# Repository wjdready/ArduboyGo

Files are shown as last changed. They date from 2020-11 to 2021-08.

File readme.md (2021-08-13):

### ArduboyGo

这是一个基于开源游戏机Arduboy制作的Arduboy Go, 这个项目由个人兴趣所产生, 目前已经完全开源包括硬件设计，外壳和代码。
目前该项目有3个版本:
  * V2 最早的一代, 不支持外置 FLASH
  
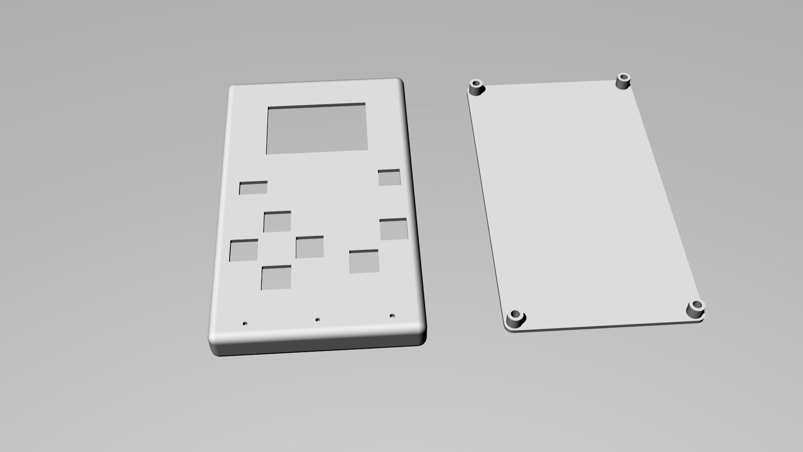
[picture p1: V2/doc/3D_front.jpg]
  

  * V3 支持外置 FLASH 加载游戏, 自定义外壳
  
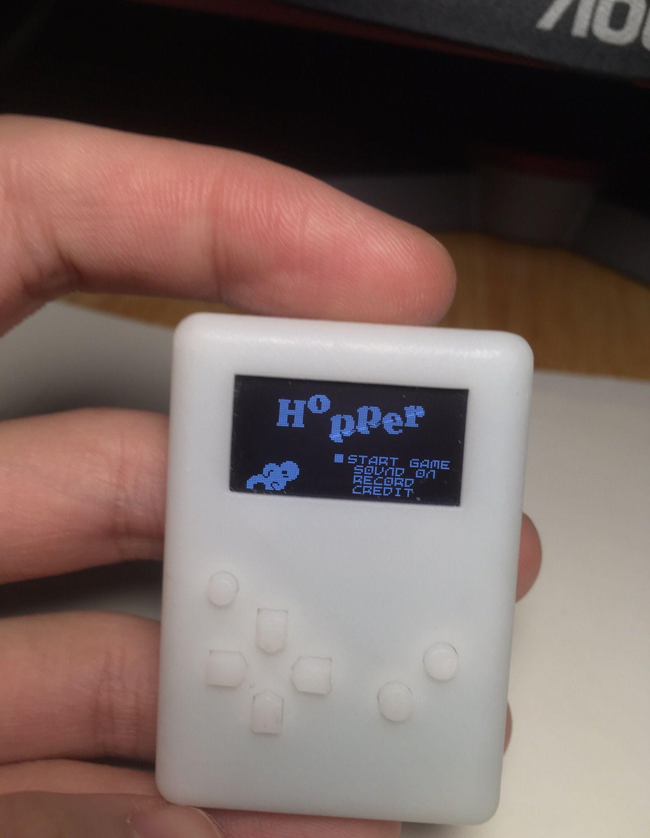
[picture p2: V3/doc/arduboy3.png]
  

  * V4 采用现成外壳, 类似于GBA
  
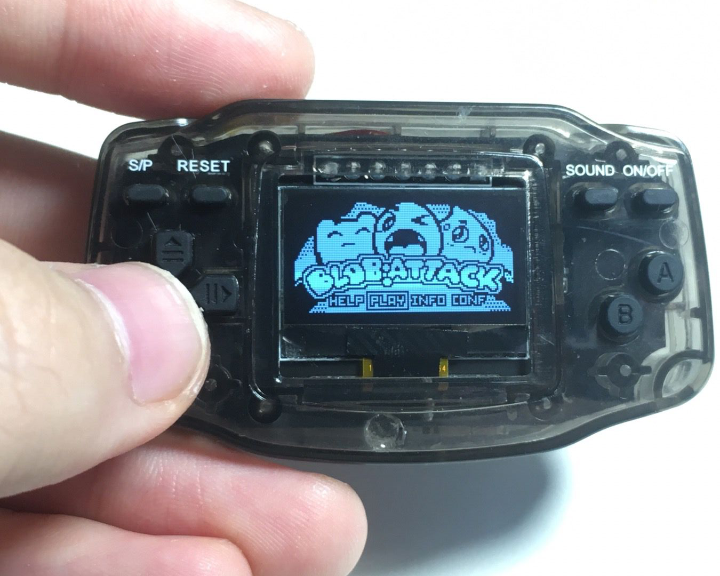
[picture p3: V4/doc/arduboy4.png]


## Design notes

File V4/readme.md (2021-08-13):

### Arduboy V4 版本
V4 版本分成两块板子, 一个是底板, 一个是 OLED, 外壳使用[现成的](https://s.taobao.com/search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)模型改造而来

  
  
* Bootloader 下载和配料清单参考 V3 版本. 因为只是外形改变, 功能和电路几乎一致. 
* 制作过程见[Bilibili](https://www.bilibili.com/video/BV1QK4y1H7EQ)

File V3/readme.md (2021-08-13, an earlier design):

### Arduboy V3 版本

该版本加入了 SPI FLASH, 可存储几百个游戏。



* 文件说明
  * Gerber 用于PCB打样
  * 3D 文件用于打印外壳
  * 可按照BOM 表提供的链接购买元件

* 制造 (非广告)
  * 可选3D 打印厂家, [未来工厂](www.wenext.cn)
  * 可选PCB加工厂, [嘉立创](www.jlc.com)
  * [bootloader 烧录器](https://item.taobao.com/item.htm?spm=a1z10.3-c-s.w4002-21223910208.10.70e96a4bl0rGBP&id=583431925839)

* Bootloader
  bootloader 加入了在主界面下按 B 键关机, 这样就不再需要电源开关了。bootloader 可直接在 Arduino 中下载, 只需把 Leonardo 的 bootloader 换arduboy3k-bootloader, 然后执行烧录引导程序：
  
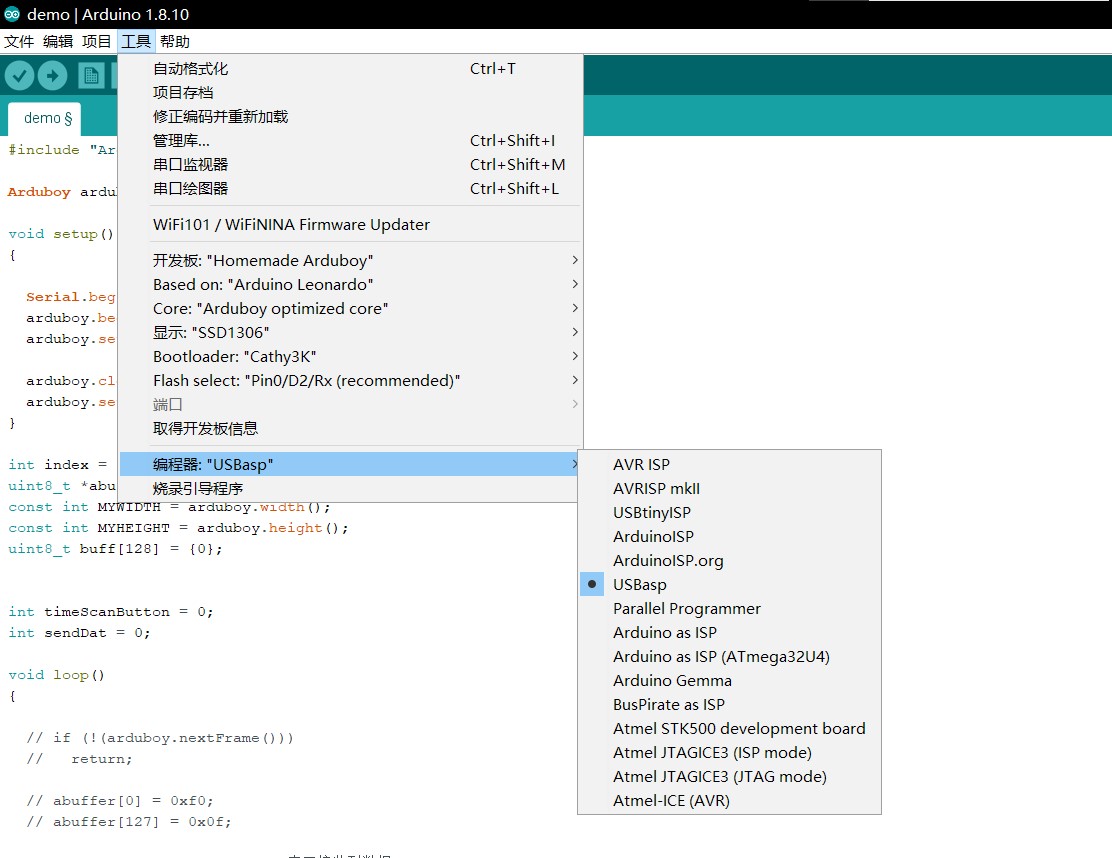
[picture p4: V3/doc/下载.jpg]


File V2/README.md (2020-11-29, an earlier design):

## Arduboy V2

这是一个基于开源游戏机Arduboy制作的Arduboy Go第二代，这个项目完全开源包括硬件设计，外壳和代码。

首先看一下制作Arduboy Go V2 需要哪些东西吧。

### PCB 板
可以通过打开项目文件夹下的 `PCB Project/outputfile` 来获得PCB加工的必要文件。当然`PCB Project`文件夹下包含了电路设计和PCB设计的全部内容。这是一个基于Altium Designer 19 设计的电路图。
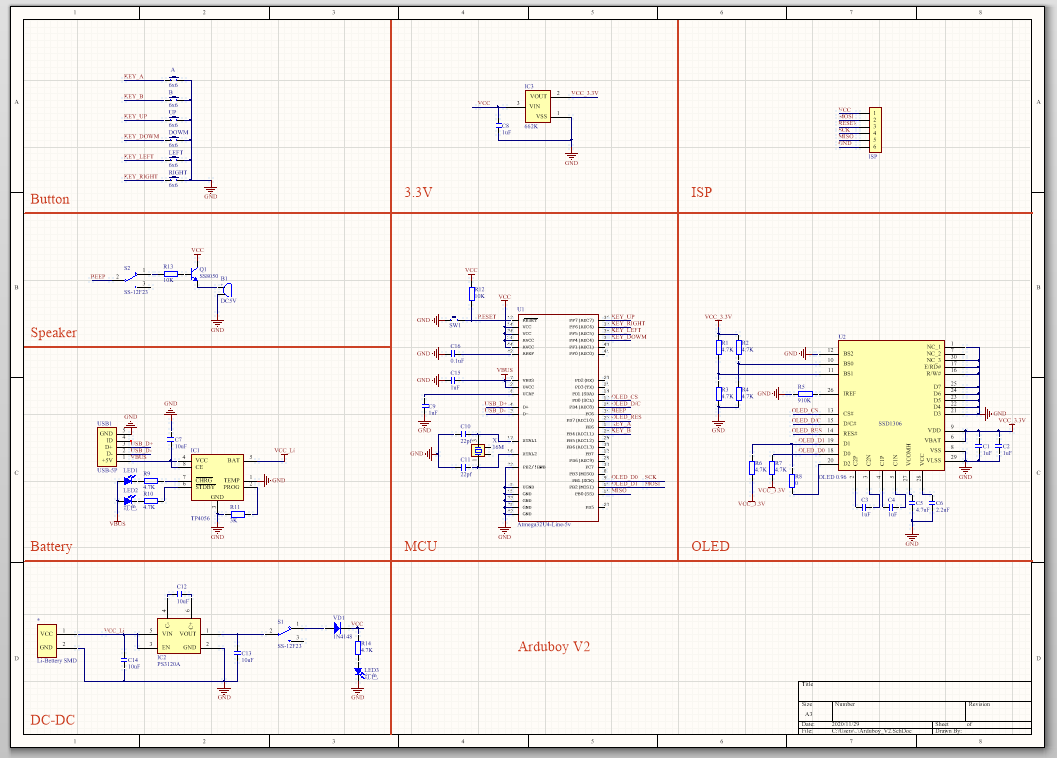
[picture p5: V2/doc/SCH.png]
SCH

其PCB 3D模型如下，正面
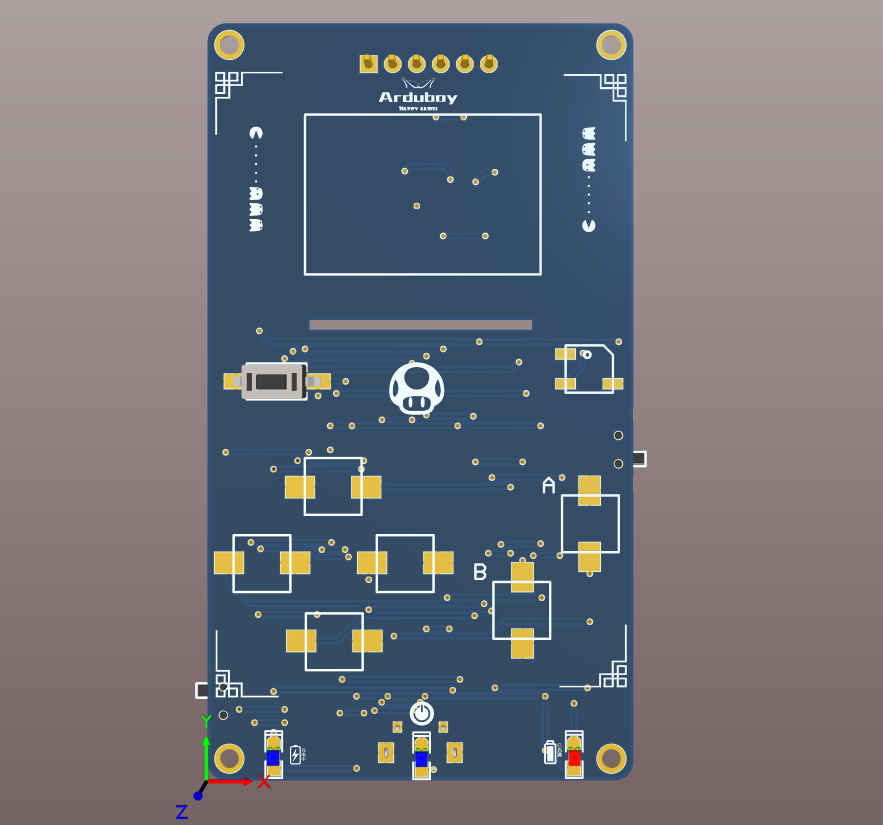
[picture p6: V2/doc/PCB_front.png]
PCB_front

背面
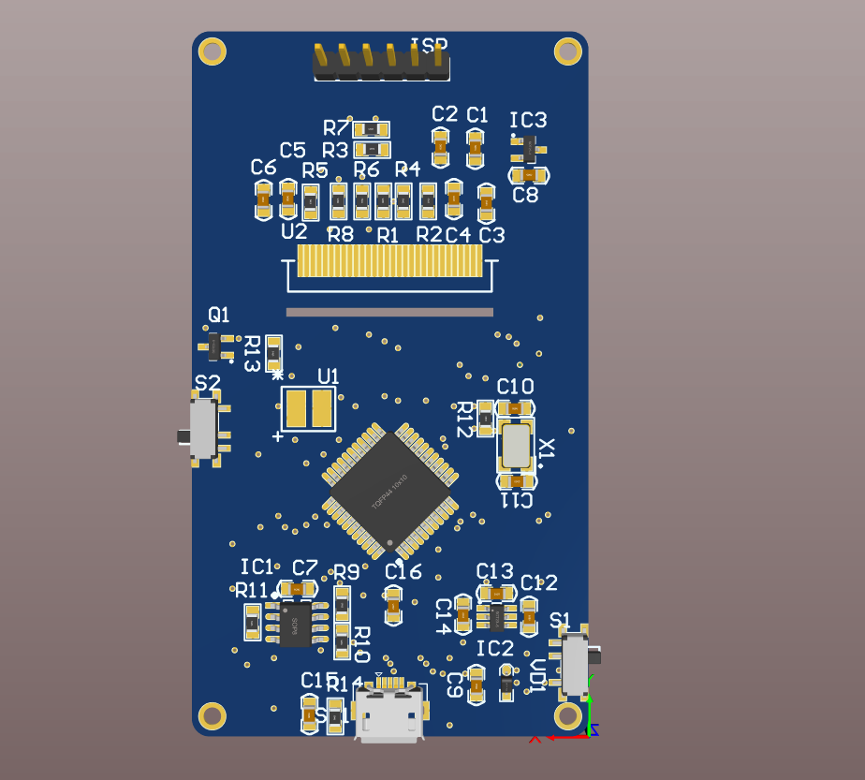
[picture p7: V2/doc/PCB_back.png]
PCB_back

如果你没有安装Altium Designer也没有关系，在`PCB Project/outputfile`里面已经包含和PCB加工的必要文件，只需要将文件夹下的`PCB.zip`提供给厂家打样就可以了。

### 元器件采购
在`PCB Project/outputfile`文件夹下的`BOM.xls` 提供了板子所需要的所有元器件的清单，甚至在后面已经包含了购买链接。
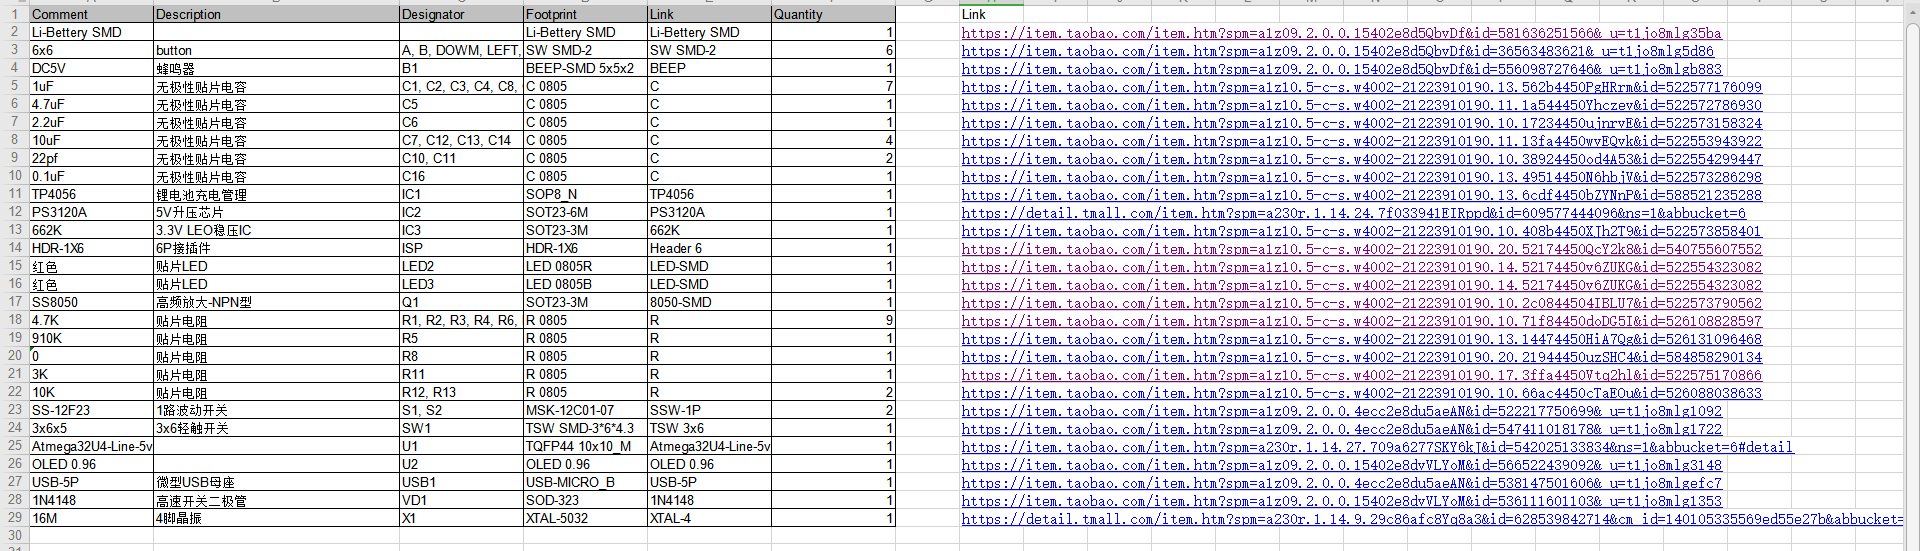
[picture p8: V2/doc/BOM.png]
BOM


### 3D 打印外壳
3D打印所需要的文件放在 `3D file` 下面，是step格式的文件。外壳预览图如下：

3D_front
反面
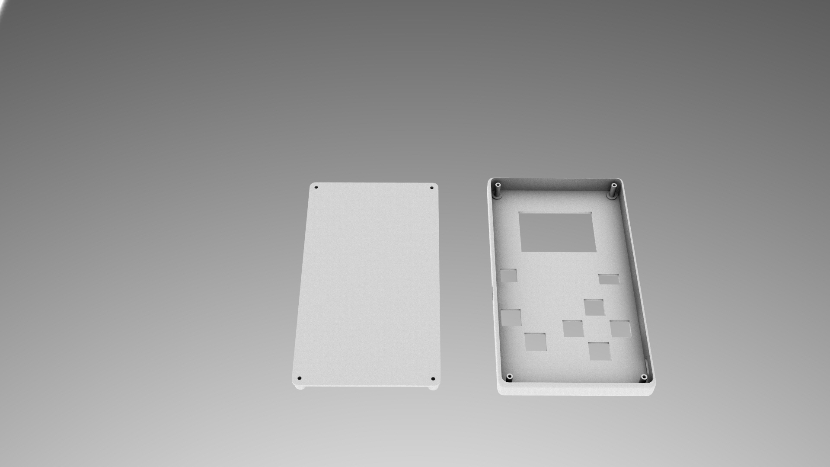
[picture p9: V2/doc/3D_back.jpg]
3D_back


### 组装调试篇
当你将PCB和3D外壳拿去工厂制作，元器件也准备齐全，并且焊接完成后第一步要做的就是下载bootloader，下载bootloader需要使用ISP下载器，你可以在网上购买如图所示的下载器，
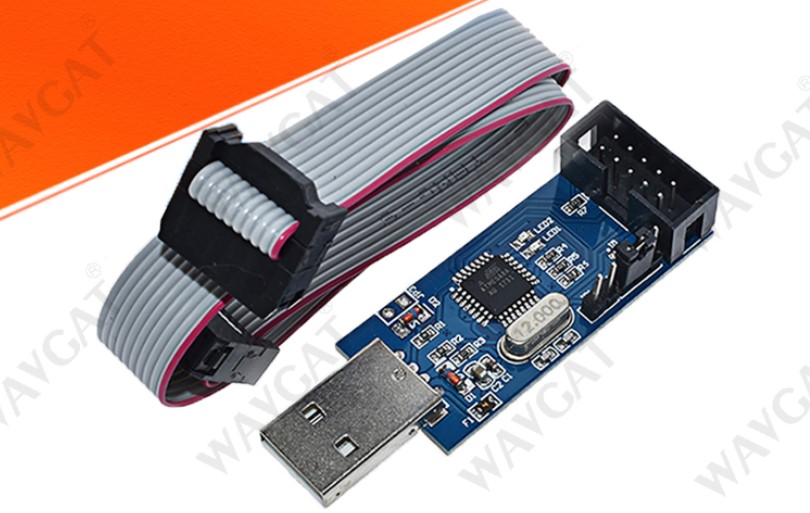
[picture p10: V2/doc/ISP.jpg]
ISP


然后使用杜邦线将下载器和板子上的接口一一接好，打开烧录软件`Progisp.exe`，设置芯片为Atmega32U4，加载`bootloader文件夹`下的`Leonardo-prod-firmware.hex`，然后加载flash
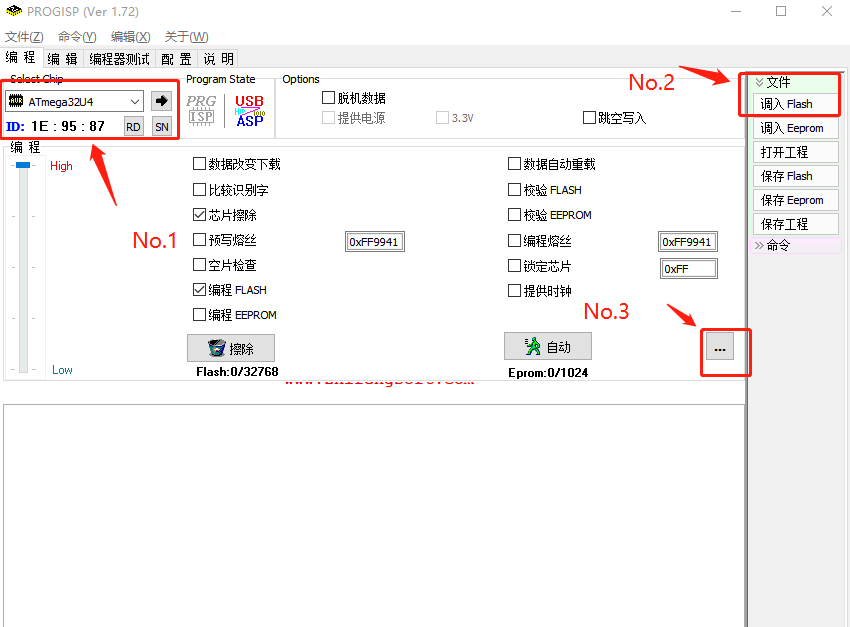
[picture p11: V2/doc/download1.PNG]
download


然后使用如下熔丝位

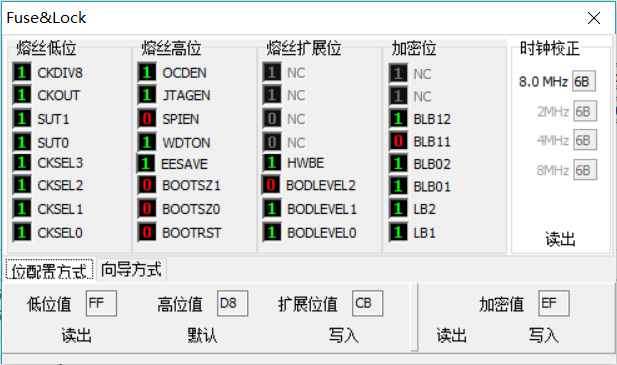
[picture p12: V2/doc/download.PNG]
download


完成后点击自动即可完成。

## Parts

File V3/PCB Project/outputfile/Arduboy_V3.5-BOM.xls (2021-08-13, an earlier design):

Comment | Description | Designator | Footprint | LibRef | Quantity | 淘宝链接
6x6 | 按键 | A, B, DOWM, LEFT, RIGHT, UP | SW SMD-4.8*4.8*0.5 | SW SMD-2 | 6 | https://item.taobao.com/item.htm?id=560211136718&ns=1&abbucket=20
DC5V | 蜂鸣器 | B1 | BEEP SMD-2 | BEEP | 1 | https://item.taobao.com/item.htm?spm=a1z09.2.0.0.9d8b2e8dhiLMWA&id=591088480905&_u=q1jo8mlg1e33
Battery | 锂电池 | BT1 | Li-Bettery SMD | Battery | 1 | https://item.taobao.com/item.htm?spm=a1z09.2.0.0.9d8b2e8dhiLMWA&id=581636251566&_u=q1jo8mlgcb86
0.1uF | 无极性贴片电容 | C2, C13, C16 | C 0603 | C | 3 | https://item.taobao.com/item.htm?spm=a1z10.3-c-s.w4002-21223910208.9.55886a4bJI9R3D&id=522573286298
1uF | 无极性贴片电容 | C3, C5, C7, C8, C14 | C 0603 | C | 5 | https://item.taobao.com/item.htm?spm=a1z10.3-c-s.w4002-21223910208.10.184f6a4bR9xQxV&id=537706477476
2.2uF | 无极性贴片电容 | C4, C9, C10, C12 | C 0603 | C | 4 | https://item.taobao.com/item.htm?spm=a1z10.3-c-s.w4002-21223910208.11.1ed76a4bUfYShi&id=537748332746
22pf | 无极性贴片电容 | C6, C11 | C 0603 | C | 2 | https://item.taobao.com/item.htm?spm=a1z10.3-c-s.w4002-21223910208.10.77426a4bstGNM5&id=522554299447
10uF | 无极性贴片电容 | C15 | C 0603 | C | 1 | https://item.taobao.com/item.htm?spm=a1z10.3-c-s.w4002-21223910208.13.65706a4bYMzriK&id=537669338432
BAT54C | 双向二极管 | D1 | SOT23-3M | BAT54C | 1 | https://item.taobao.com/item.htm?spm=a1z10.3-c-s.w4002-21223910208.10.62606a4bfGLqWp&id=578704025682
MSMD200-8V 2A | 贴片保险丝 | F1 | FU 0603 | FU | 1 | https://item.taobao.com/item.htm?spm=a1z09.2.0.0.9d8b2e8dhiLMWA&id=560313507871&_u=q1jo8mlg39a8
W25Qxx | 外置Flash | IC1 | SOP8W_N | W25Qxx | 1 | https://item.taobao.com/item.htm?spm=a1z10.3-c-s.w4002-21223910208.16.71556a4b2r4bew&id=564591610272
 | 贴片LED | LED1 | LED 0603B | LED-SMD | 1 | https://item.taobao.com/item.htm?spm=a1z09.2.0.0.9d8b2e8dhiLMWA&id=522573309525&_u=q1jo8mlg1bb3
SS8050 | 高频放大-NPN型 | Q1 | SOT23-3M | 8050-SMD | 1 | https://item.taobao.com/item.htm?spm=a1z09.2.0.0.9d8b2e8dhiLMWA&id=522573790562&_u=q1jo8mlgf791
10K | 贴片电阻 | R1, R3 | R 0603 | R | 2 | https://item.taobao.com/item.htm?spm=a1z10.3-c-s.w4002-21223910208.10.1b466a4b9HvAFs&id=525777943950
910K | 贴片电阻 | R2 | R 0603 | R | 1 | https://item.taobao.com/item.htm?spm=a1z10.3-c-s.w4002-21223910208.10.62206a4bcmwDK2&id=525898324437
3.3K | 贴片电阻 | R4, R8 | R 0603 | R | 2 | https://item.taobao.com/item.htm?spm=a1z10.3-c-s.w4002-21223910208.10.beab6a4b2nolkO&id=525826788004
1.5K | 贴片电阻 | R5 | R 0603 | R | 1 | https://item.taobao.com/item.htm?spm=a1z10.3-c-s.w4002-21223910208.9.59806a4b7uZvfL&id=525814237339
10R | 贴片电阻 | R6, R7 | R 0603 | R | 2 | https://item.taobao.com/item.htm?spm=a1z10.3-c-s.w4002-21223910208.10.58526a4bOVHXmr&id=525724626983
OLED 0.96 |  | U1 | OLED 0.96 | OLED 0.96 | 1 | https://item.taobao.com/item.htm?spm=a1z10.3-c-s.w4002-21223910208.10.7d366a4bapGfnZ&id=562073634567
Atmega32U4-Line-5v |  | U2 | TQFP44 10x10_M | Atmega32U4-Line-5v | 1 | https://item.taobao.com/item.htm?spm=a1z10.3-c-s.w4002-21223910208.15.25196a4boc6TNb&id=563263189241
LTC4054 | 充电管理 | U3 | SOT23-5M | LTC4054 | 1 | https://item.taobao.com/item.htm?spm=a1z10.3-c-s.w4002-21223910208.9.67466a4bi1a5Xc&id=533845076633
SPX3819 | 3.3V LDO 稳压 | U4 | SOT23-5N | SPX3819 | 1 | https://item.taobao.com/item.htm?spm=a1z10.3-c-s.w4002-21223910208.10.24376a4bnUat9Y&id=522554991270
Type-C | USB 3.1 单排16PIN四脚插板(L=7.35) 一体式MD | USB1 | Type C 16p | Type-C Socket | 1 | https://item.taobao.com/item.htm?spm=a1z09.2.0.0.9d8b2e8dhiLMWA&id=573090887123&_u=q1jo8mlgf89b
16MHz | 4脚晶振 | X1 | XTAL-3225 | XTAL-4 | 1 | https://item.taobao.com/item.htm?spm=a1z09.2.0.0.9d8b2e8dhiLMWA&id=522572378852&_u=q1jo8mlg49f0

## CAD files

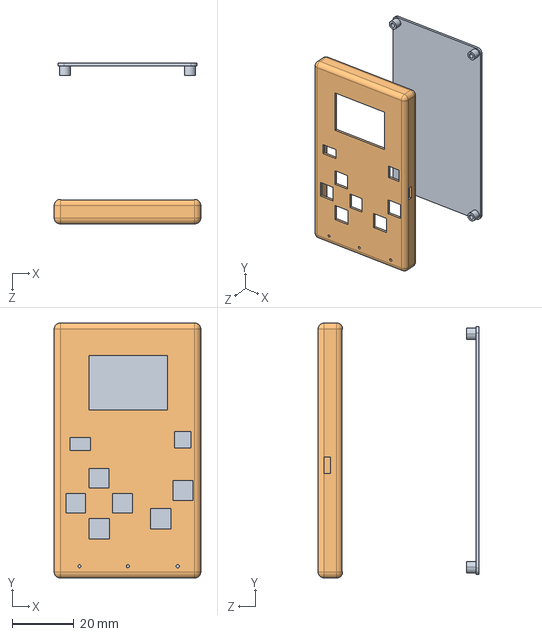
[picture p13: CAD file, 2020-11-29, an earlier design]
V2/3D file/Arduboy V2 3D.STEP
47.4 x 82.4 x 52.0 mm

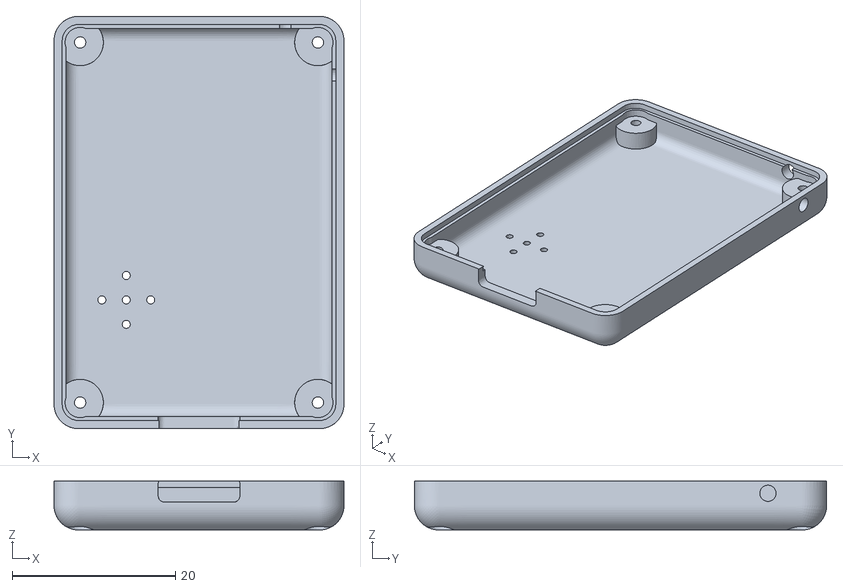
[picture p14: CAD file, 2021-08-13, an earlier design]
V3/3D fIle/stl/Arduboy_V3.5-5 下壳.stl
35.6 x 50.6 x 6.00

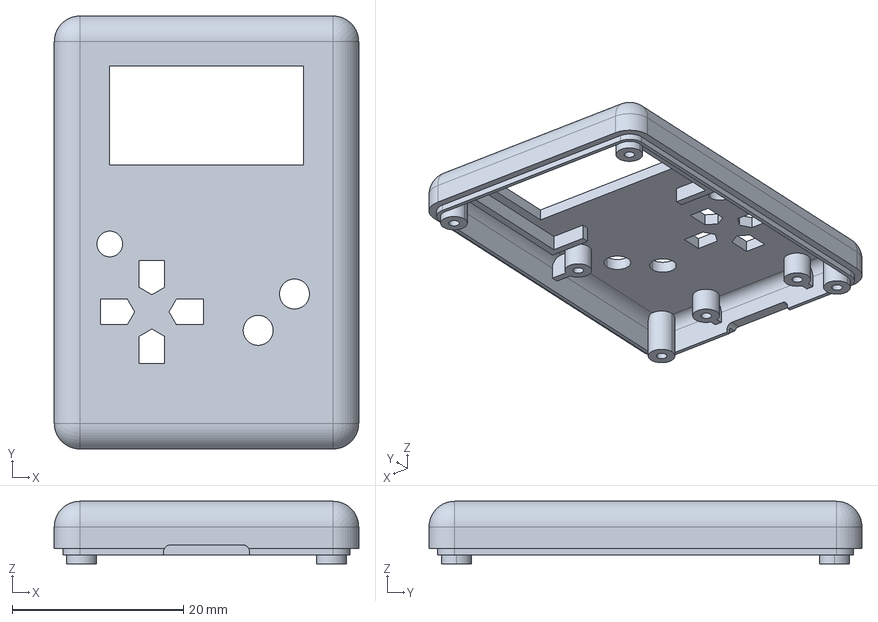
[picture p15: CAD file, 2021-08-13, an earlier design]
V3/3D fIle/stp/Arduboy_V3.5-4 上壳.stp
35.6 x 50.6 x 7.30 mm

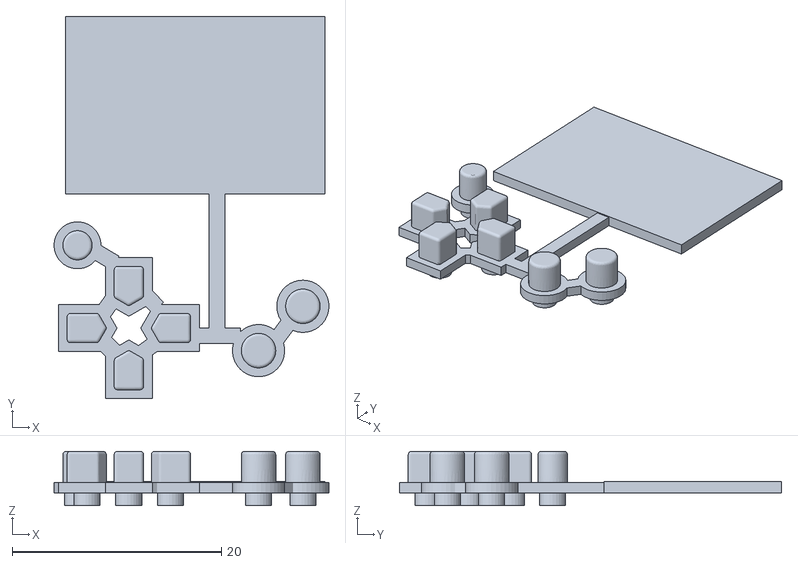
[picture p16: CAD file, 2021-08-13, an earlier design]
V3/3D fIle/stl/Arduboy_V3.5-5 按键.stl
26.3 x 36.6 x 5.20

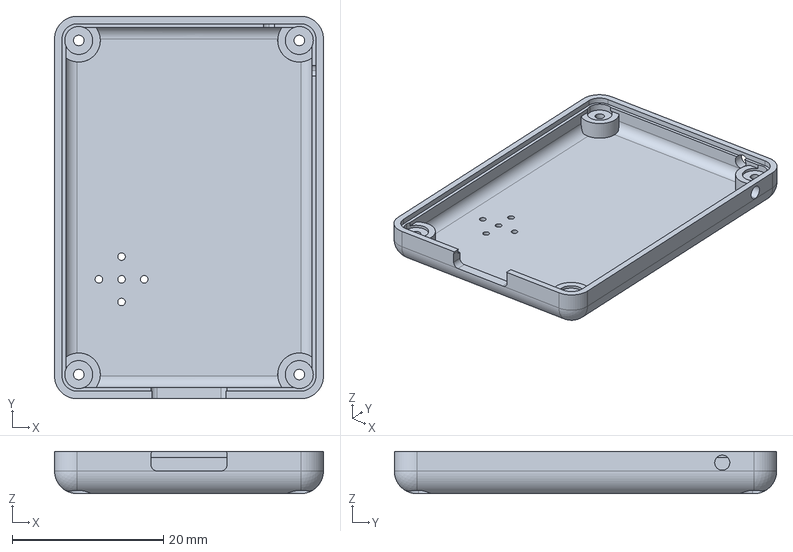
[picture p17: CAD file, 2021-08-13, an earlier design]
V3/3D fIle/stp/Arduboy_V3.5-4 下壳.stp
35.6 x 50.6 x 5.60 mm

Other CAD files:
V3/3D fIle/stl/Arduboy_V3.5-5 上壳.stl
V3/3D fIle/stp/Arduboy_V3.5-4 按键.stp

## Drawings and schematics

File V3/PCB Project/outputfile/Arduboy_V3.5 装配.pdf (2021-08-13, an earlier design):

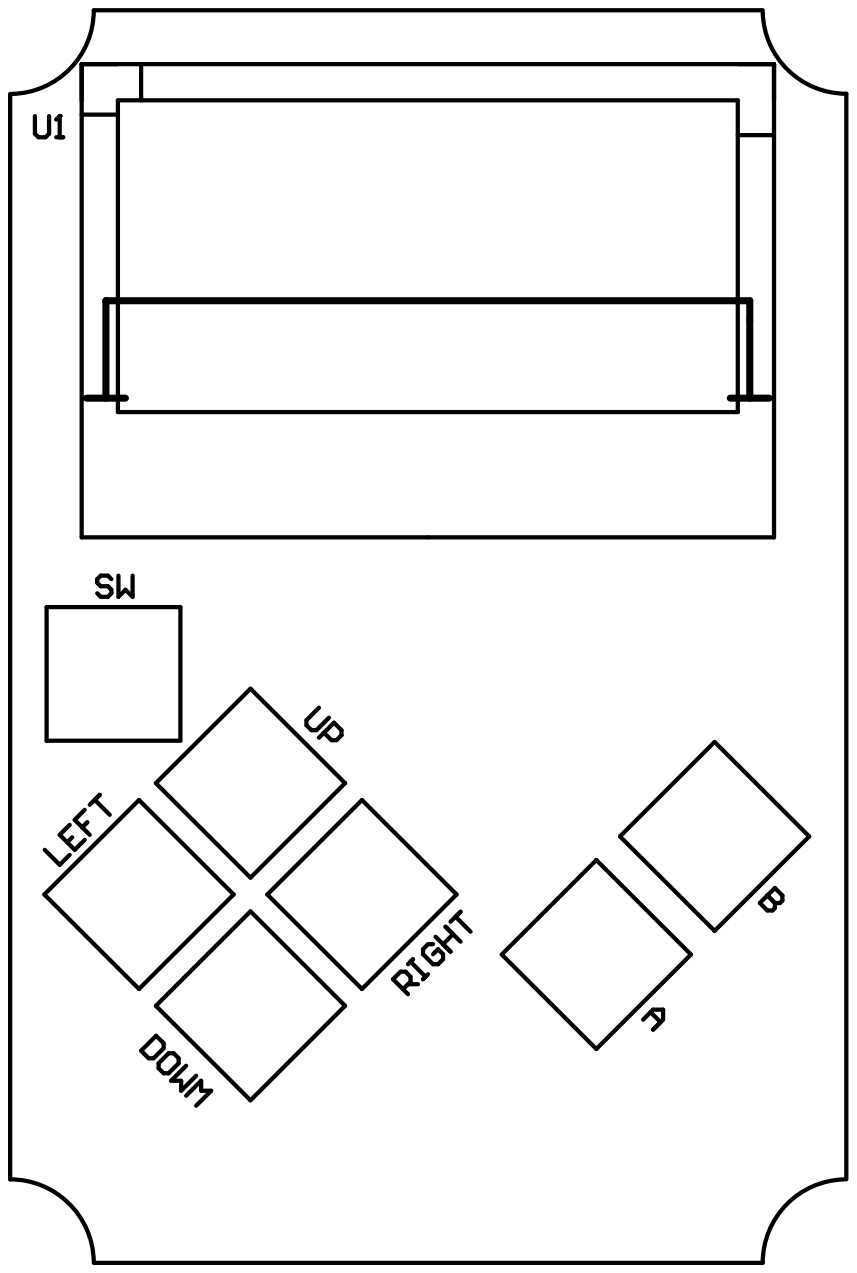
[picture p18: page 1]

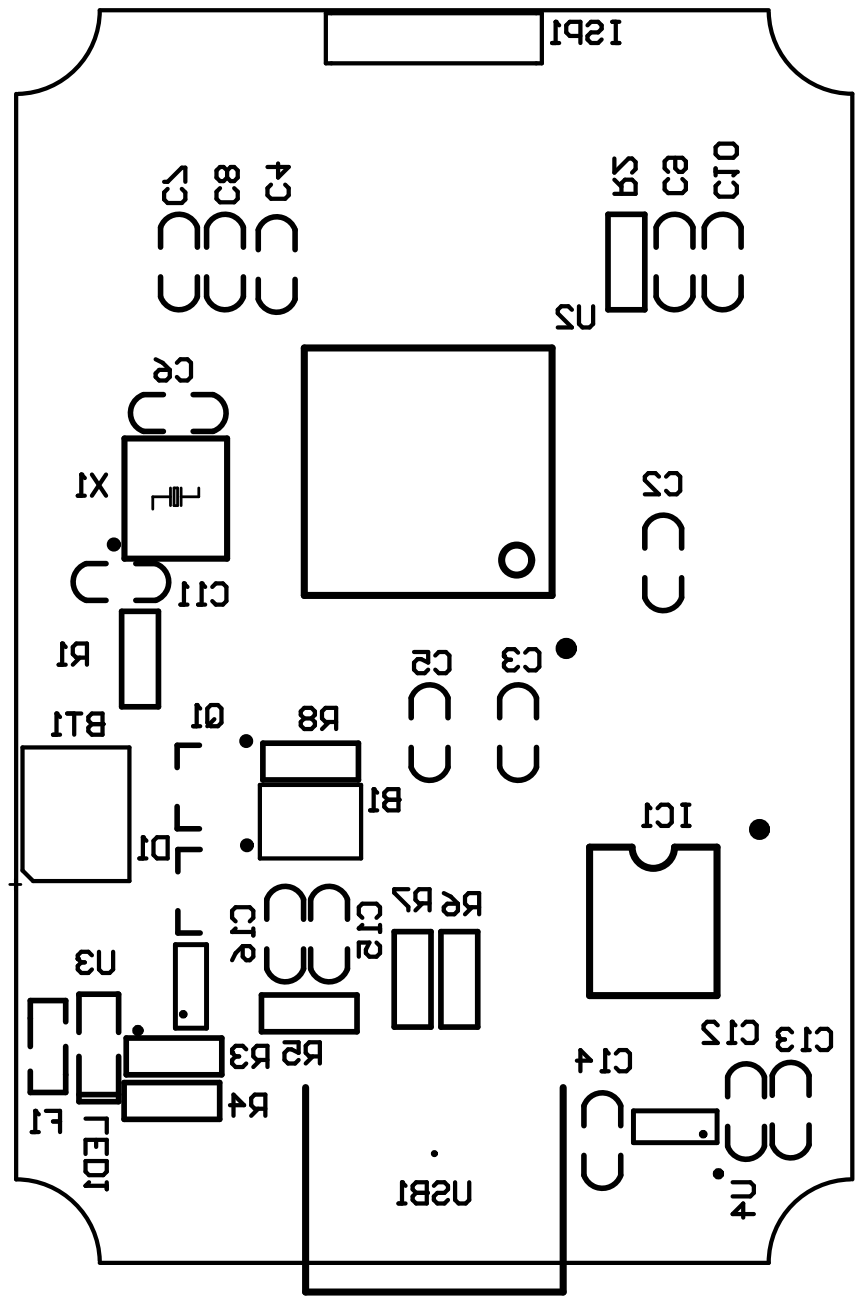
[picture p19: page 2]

Board Stack Report

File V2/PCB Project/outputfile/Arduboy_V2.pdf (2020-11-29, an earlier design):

3.3V | ISP

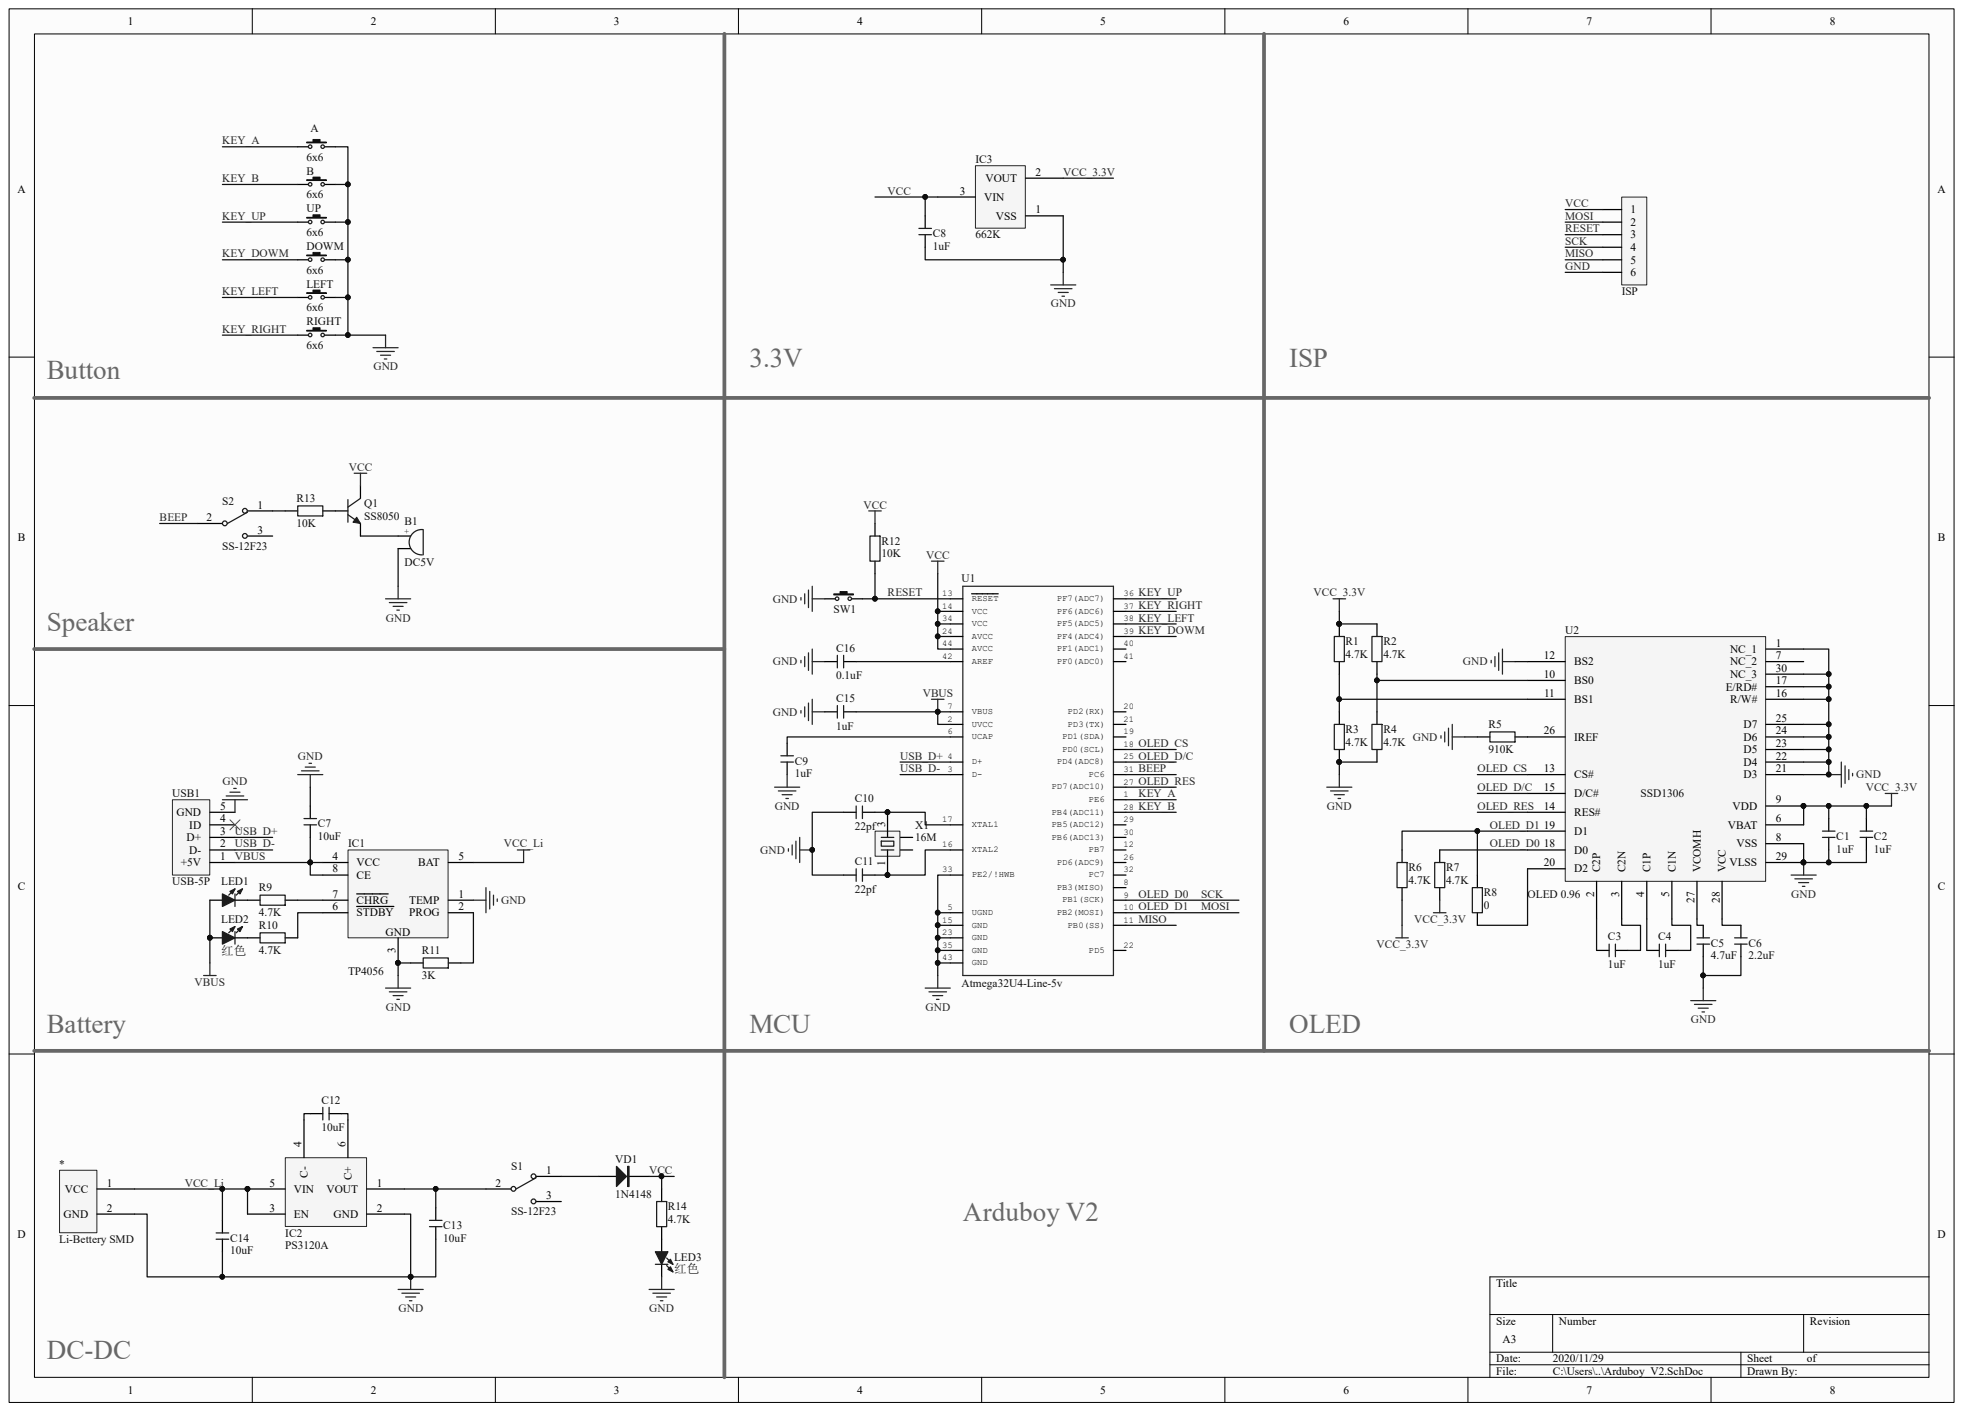
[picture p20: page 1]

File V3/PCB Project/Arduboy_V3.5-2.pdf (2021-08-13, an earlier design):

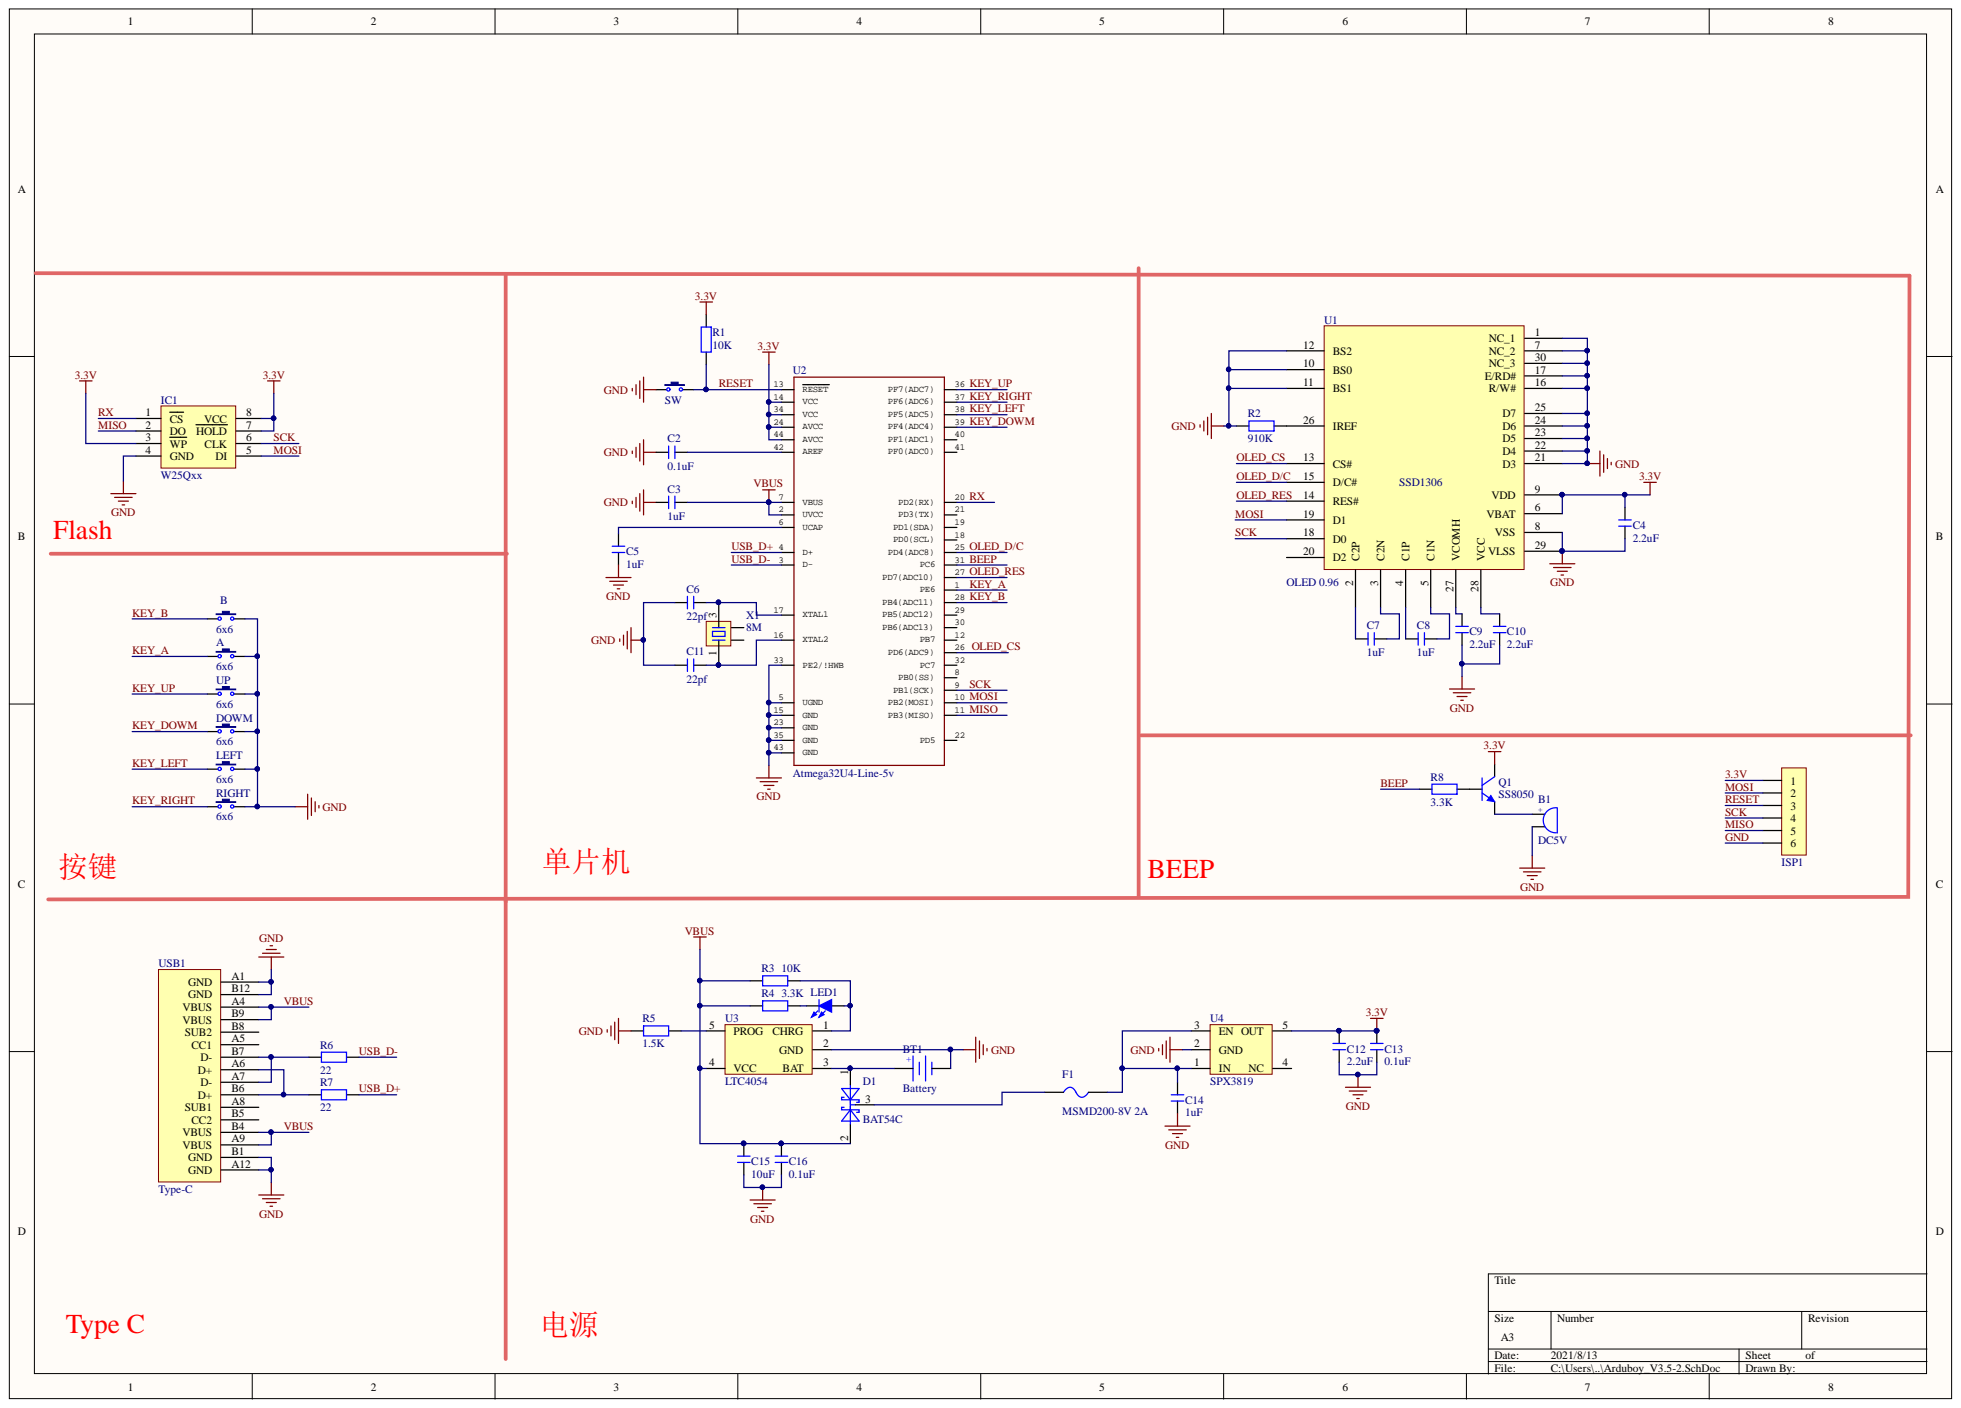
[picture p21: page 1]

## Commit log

2020-11-29 all done
    [Arduboy V2 3D.STEP, Arduboy_V2.PrjPcb, Arduboy_V2.SchDoc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]
2021-08-13 加入了V3版 和 V4 版
    [Arduboy V2 3D.STEP, Arduboy_V2.PrjPcb, Arduboy_V2.SchDoc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]
2022-03-12 support both 44-pin QFN and 44-pin TQFP
    [Arduboy_V2.PrjPcb, Arduboy_V3.5-2.PrjPCB, Arduboy_V3.5-2.SchDoc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]
